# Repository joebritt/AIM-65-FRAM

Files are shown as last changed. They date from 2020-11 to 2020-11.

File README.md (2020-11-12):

# AIM-65-FRAM

Nonvolatile FRAM memory replacement for 2332 ROM used by the Rockwell AIM-65.



<p align="middle">
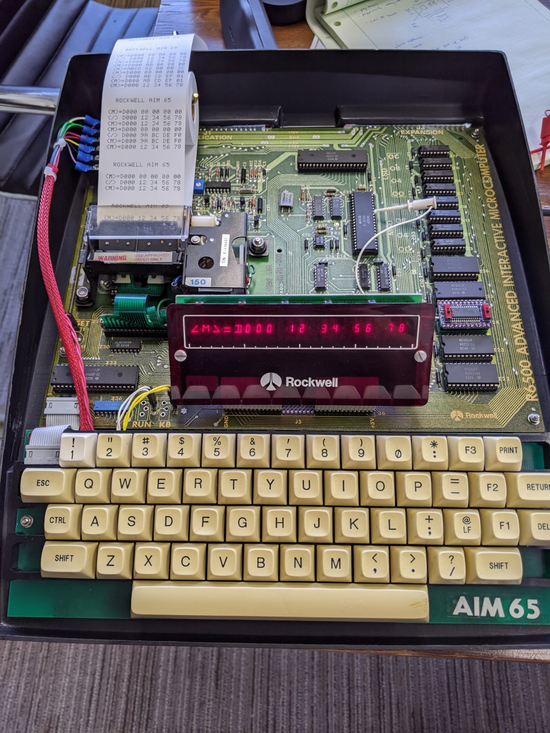
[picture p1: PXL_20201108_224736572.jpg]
  
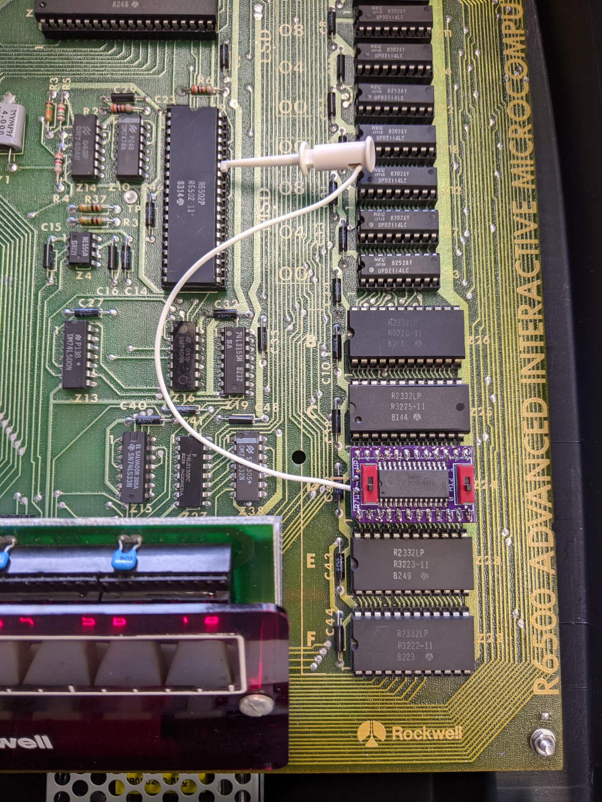
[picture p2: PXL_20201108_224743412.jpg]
  
</p>

This board plugs into any of the 5 2332 AIM-65 ROM sockets. 
A lead to the 6502 R/W signal is needed for writing to the FRAM.

A Write Protect switch allows disconnecting the R/W signal so that the FRAM truly behaves like a ROM.

The FRAM is 8KB, and the 2332 is only 4KB. A switch selects whether A12 is pulled high or low, giving 2 banks of 4KB. 
A12 may also be tied to an I/O pin, such as from one of the 6522s, to allow programmatic bank selection.

While the memory is true read/write, the Single Step circuitry on the AIM-65 requires A15, A14, and A13 to all be LOW.
As a result, you can't single-step through code in this memory.

Not directly related, but I also had to make new LED display supports for my AIM-65. A tested (in use now!)
3D-printable design can be found 
<a href="https://cad.onshape.com/documents/efebfeba35798ffd247abe96/w/842ecc41860fff750f9e59dd/e/60049825f7dbb6890abf0c50">here.</a>

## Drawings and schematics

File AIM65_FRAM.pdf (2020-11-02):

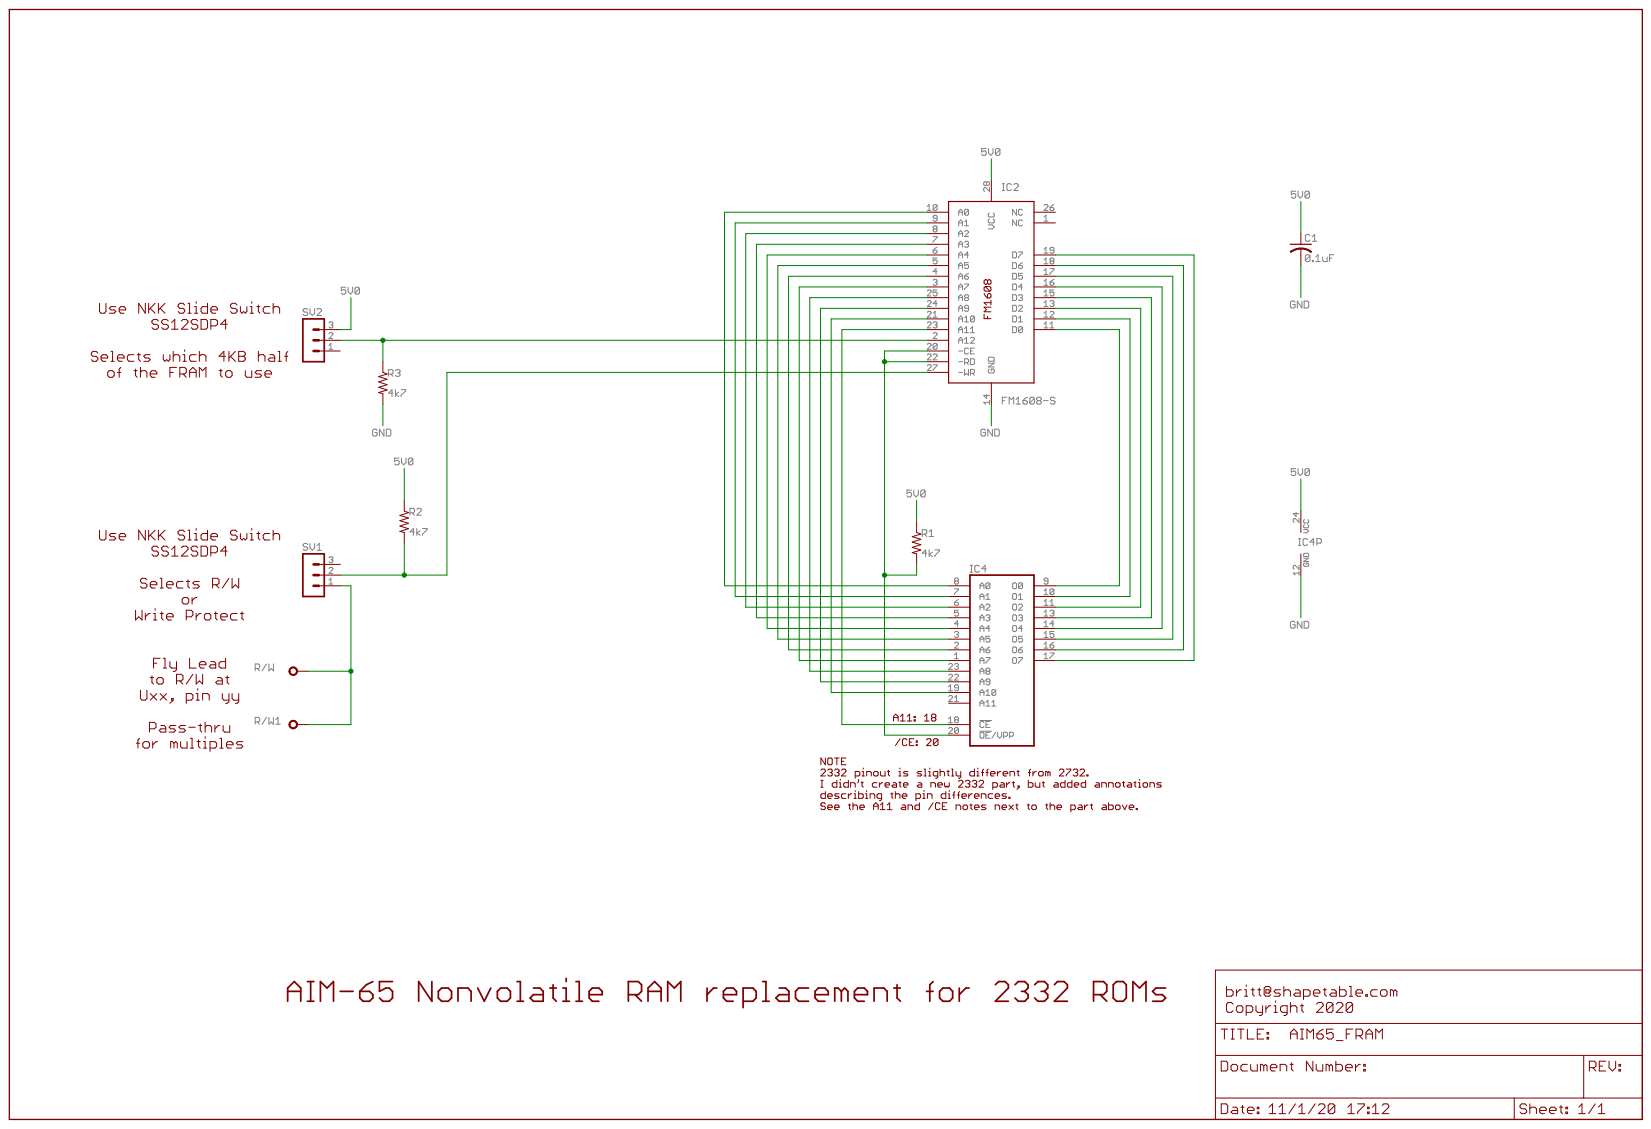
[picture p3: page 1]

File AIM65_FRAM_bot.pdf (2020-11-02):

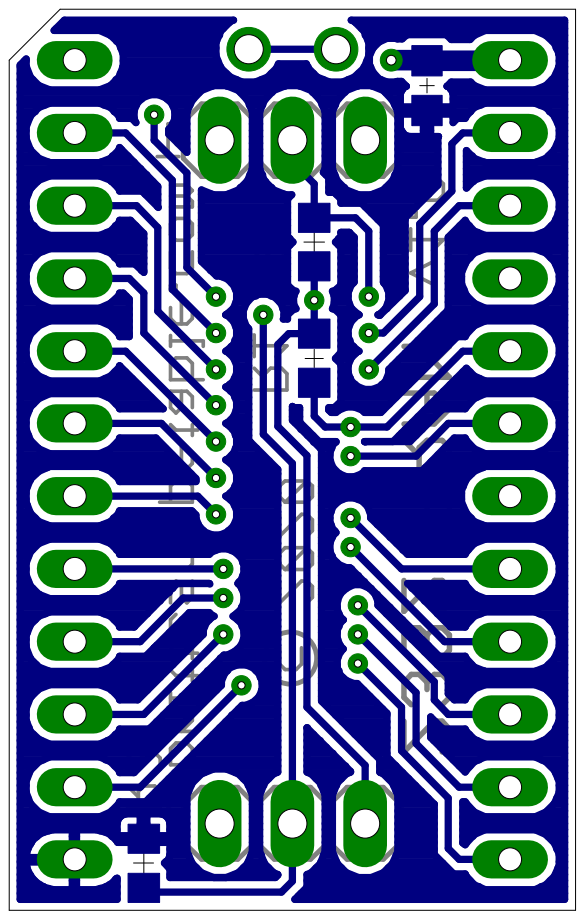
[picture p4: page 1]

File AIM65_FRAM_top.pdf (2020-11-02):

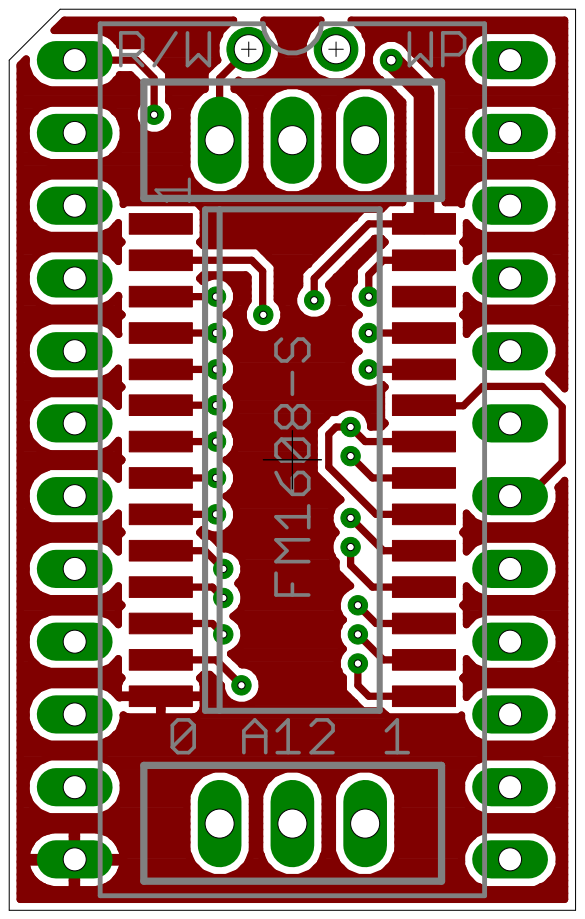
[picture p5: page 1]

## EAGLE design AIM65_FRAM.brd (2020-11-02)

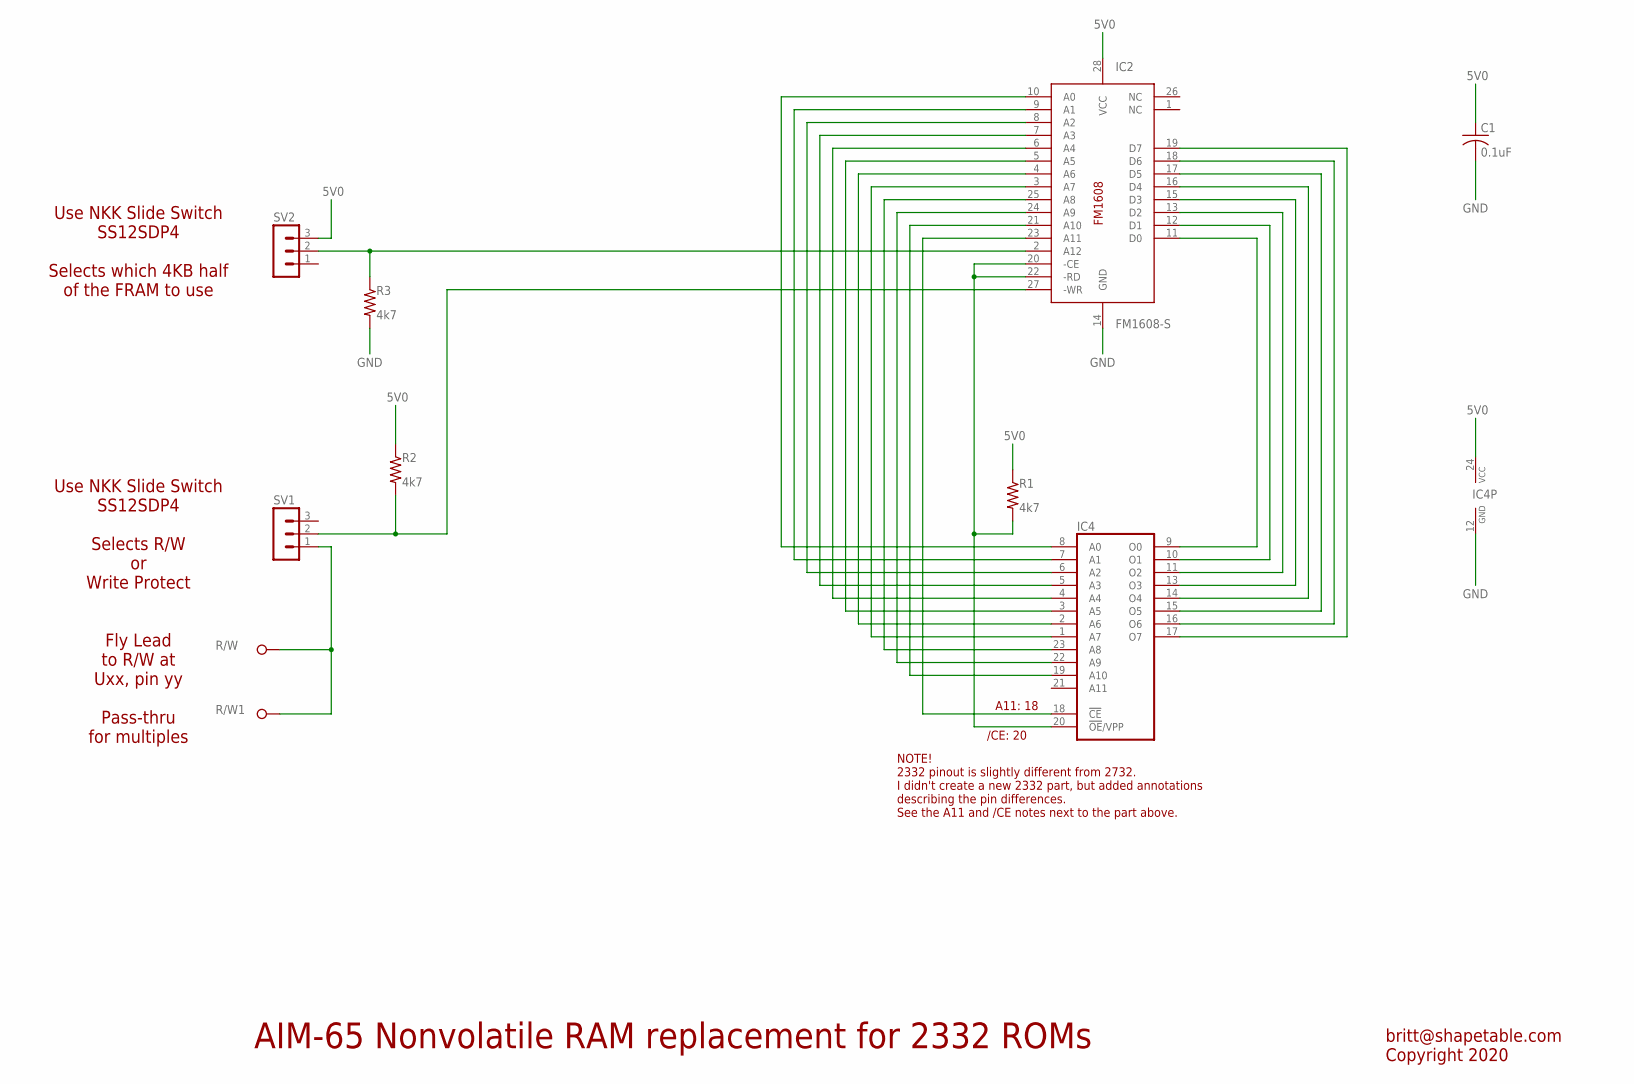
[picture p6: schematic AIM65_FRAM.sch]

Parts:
C1: 0.1uF; C0603K
IC2: FM1608-S; SO-28W
IC4: 2732; DIL24
R1, R2, R3: 4k7; R0603
R/W, R/W1: JOE-TP-BIG; JOE-TP-PKG-BIG
SV1, SV2: MA03-1

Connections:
5V0: C1.1, IC2.28 (VCC), IC4.24 (VCC), R1.1, R2.1, SV2.3
GND: C1.2, IC2.14 (GND), IC4.12 (GND), R3.2
unnamed: IC2.10 (A0), IC4.8 (A0)
unnamed: IC2.9 (A1), IC4.7 (A1)
unnamed: IC2.8 (A2), IC4.6 (A2)
unnamed: IC2.7 (A3), IC4.5 (A3)
unnamed: IC2.6 (A4), IC4.4 (A4)
unnamed: IC2.5 (A5), IC4.3 (A5)
unnamed: IC2.4 (A6), IC4.2 (A6)
unnamed: IC2.3 (A7), IC4.1 (A7)
unnamed: IC2.25 (A8), IC4.23 (A8)
unnamed: IC2.24 (A9), IC4.22 (A9)
unnamed: IC2.21 (A10), IC4.19 (A10)
unnamed: IC2.23 (A11), IC4.18 (!CE)
unnamed: IC2.2 (A12), R3.1, SV2.2
unnamed: R/W.1, R/W1.1, SV1.1
unnamed: IC2.20 (-CE), IC2.22 (-RD), IC4.20 (!OE!/VPP), R1.2
unnamed: IC2.27 (-WR), R2.2, SV1.2
unnamed: IC2.19 (D7), IC4.17 (O7)
unnamed: IC2.18 (D6), IC4.16 (O6)
unnamed: IC2.17 (D5), IC4.15 (O5)
unnamed: IC2.16 (D4), IC4.14 (O4)
unnamed: IC2.15 (D3), IC4.13 (O3)
unnamed: IC2.13 (D2), IC4.11 (O2)
unnamed: IC2.12 (D1), IC4.10 (O1)
unnamed: IC2.11 (D0), IC4.9 (O0)

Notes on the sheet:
Use NKK Slide Switch SS12SDP4 Selects which 4KB half of the FRAM to use
Fly Lead to R/W at Uxx, pin yy Pass-thru for multiples
Use NKK Slide Switch SS12SDP4 Selects R/W or Write Protect
A11: 18
/CE: 20
NOTE! 2332 pinout is slightly different from 2732. I didn't create a new 2332 part, but added annotations describing the pin differences. See the A11 and /CE notes next to the part above.
AIM-65 Nonvolatile RAM replacement for 2332 ROMs
britt@shapetable.com Copyright 2020

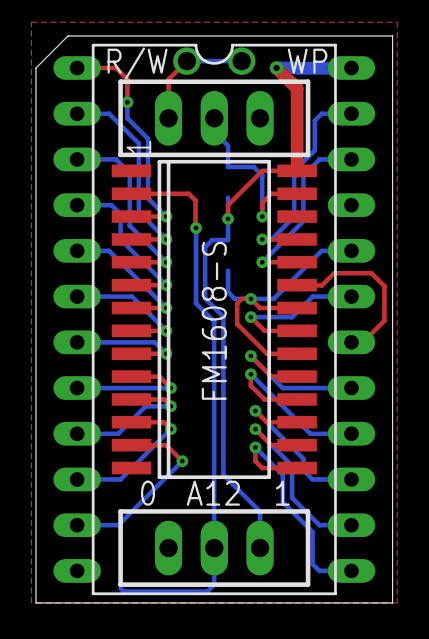
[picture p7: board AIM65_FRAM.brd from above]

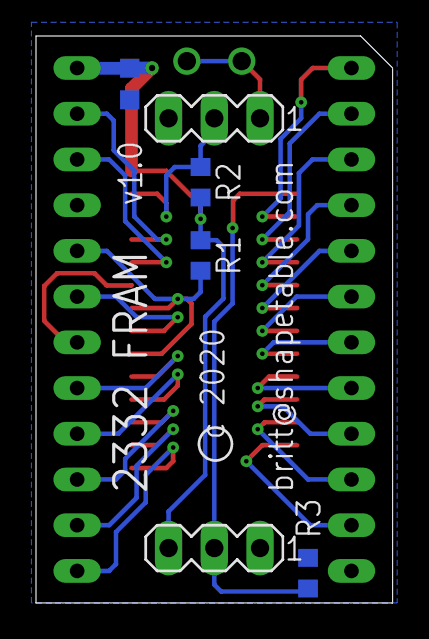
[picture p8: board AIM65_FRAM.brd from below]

Board: 2 copper layers, 19.8 x 31.5 mm, 10 parts (6 on the bottom side), 26 nets.
